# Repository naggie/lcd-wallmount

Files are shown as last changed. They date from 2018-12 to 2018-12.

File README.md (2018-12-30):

Unibezel is a tough, parametric bezel suitable for mounting a touchscreen on to
any wall. It has vents for passive cooling, holes for screws and cut-outs for
cabling. It is an evolution of my last [Amazon fire tablet mounting
system.][1]. It is built using [OpenSCAD][4].

The OpenSCAD file (bezel.scad) is set up to fit the [official Pi LCD
display][2] with a reversed [Raspberry Pi 3][2] behind, with space for a generic 5v
802.11af PoE adaptor. There are also configurations for the Amazon Fire 5
tablet -- though, beware -- do not leave the battery in the tablet when wall
mounted as it is a fire hazard. It is possible to power the tablet without the
battery providing the battery interface board is left connected.

The design has optional cut-outs for a 20mm conduit entry point, as well as
slopes on the top and bottom to increase toughness. Edges are mostly rounded
and chamfered to reduce stress concentration.

pi-display-bezel.stl is provided for your convenience. It is a pre-built stl of
the default configuration suitable for the official Pi display as above.

This design is the result of dozens of printed iterations. If you use this
design, please attribute the original repository at
https://github.com/naggie/unibezel

# Finishing process

I've printed this design with PLA on my 3d printer. It seems to work well -- no
supports are required when it is printed front-down.

Stop at step 5 if you're happy with a mediocre finish.

1. Coat generously with flexible car body filler (2 part, toxic!)
1. Sand flat with 80 or 120, round off sharp edges a small amount. Beware of dust.
1. Continue with P240, P400, P600 etc
1. Plastic Primer (2 or 3)
1. Gloss black (2 or 3)
1. Lacquer 3 or 4 coats
1. Sand P2000, P4000, P5000
1. Polish (car polish is good)
1. Wax
1. Detailer

# Images (Raspberry Pi display)

<p align="center">
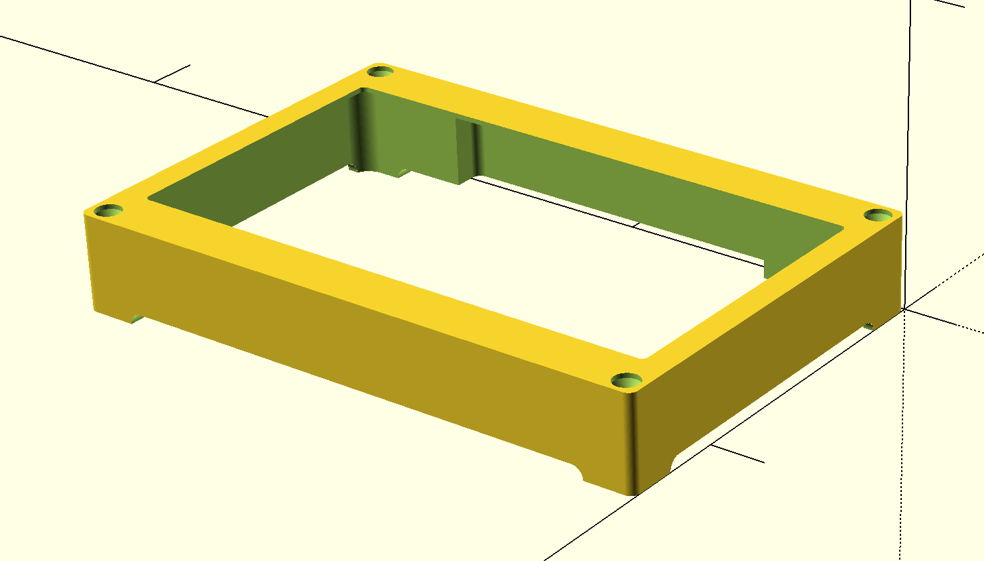
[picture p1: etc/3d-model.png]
  
</p>

<p align="center">
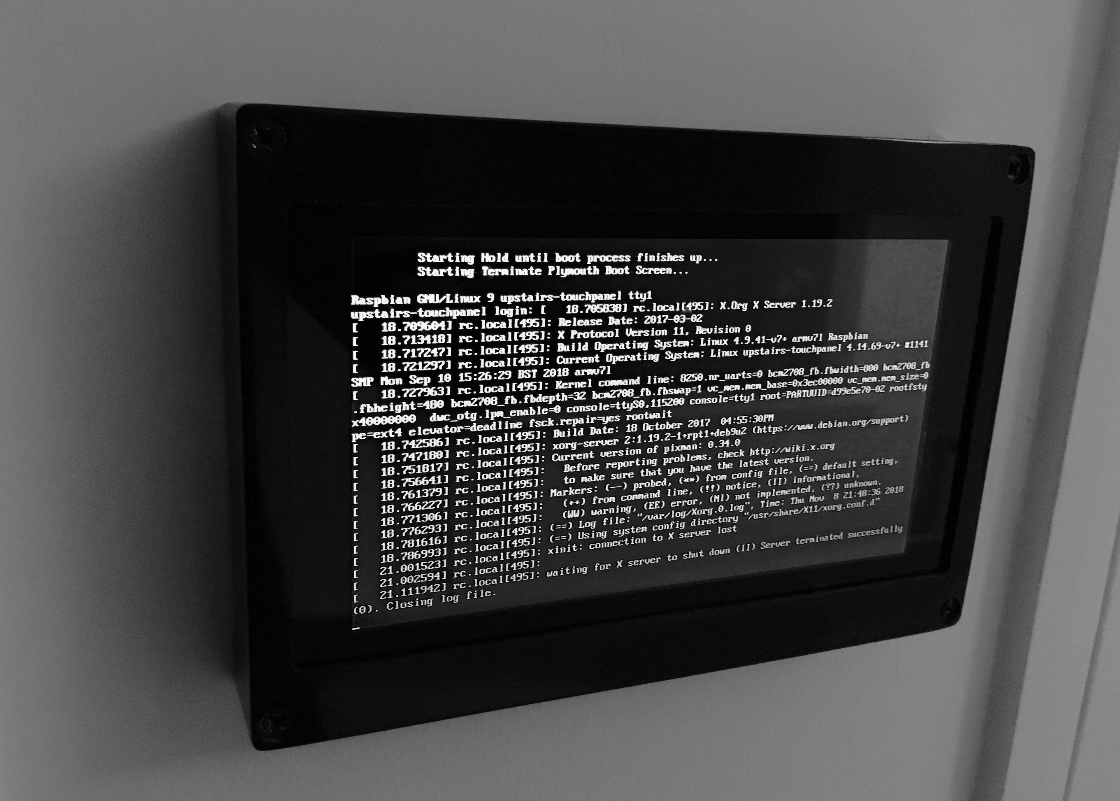
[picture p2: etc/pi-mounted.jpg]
  
</p>

<p align="center">
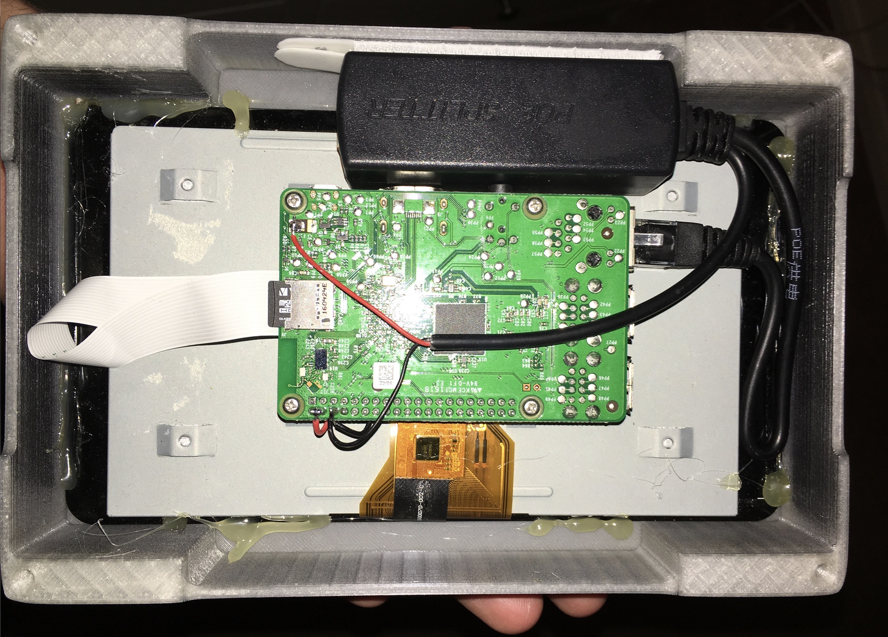
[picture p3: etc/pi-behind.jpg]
  
</p>

[1]: https://callanbryant.co.uk/post/dshome-2-control-panels/
[2]: https://www.raspberrypi.org/products/raspberry-pi-touch-display/
[3]: https://www.raspberrypi.org/products/raspberry-pi-3-model-b-plus/
[4]: https://www.openscad.org/

----

<br />This work is
licensed under a <a rel="license"
href="http://creativecommons.org/licenses/by/4.0/">Creative Commons Attribution
4.0 International License</a>.

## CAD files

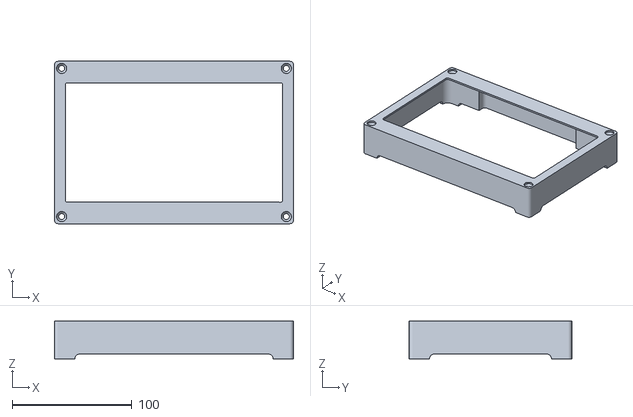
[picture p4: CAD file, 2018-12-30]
pi-display-bezel.stl
200.0 x 136.0 x 31.6

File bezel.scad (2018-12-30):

// https://github.com/OskarLinde/scad-utils/blob/master/morphology.scad
// empty in in /Users/<user>/Documents/OpenSCAD/libraries
// NOTE: Something I realised is symmetry is more important than spatial
// efficacy.
$fn = 200;

module rounded_cube(x,y,z,r) {
    linear_extrude(height=z) translate([r,r,0]) offset(r=r) square([x-2*r,y-2*r]);
}

// basic portrait bezel
// set tolerance to leave an appropriate gap for your manufacturing method
// https://www.3dprint-uk.co.uk/machine-accuracy/
// Tolerance is only given for the critical part, the tablet inlay
module bezel(
    // size of tablet/display (bounding box)
    x,y,z,
    // plastic covering screen: top, right, yframe, left (like CSS)
    // use to cover corner radius of tablet/display
    // use to cover non-display areas of tablet/display
    overhang=[3,3,3,3],
    // thickness of plastic covering screen
    rim_depth=2,
    // how far to move the rim down, use only to mount a flush screen from the front
    rim_inset=0,
    // frame intersecting y-axis
    yframe=10,
    // frame intersecting x-axis
    xframe=5,
    // move position of tablet/display along x-axis/y-axis to center a display with non-symmetric edges
    xshift=0,
    yshift=0,
    // internal cut out radius -- could match tablet/display corners. Important for flush displays
    internal_radius=2,
    // radius of rim, or support for flush screen
    rim_radius=2,
    slopes=false
) {


    difference() {
        hull() {
            if (slopes) {
                // experimental inefficient but cool looking slopes!
                translate([0, -z, 0]) rounded_cube(x+xframe*2, y+yframe*2 + 2*z, 6, 3);
            }

            // bounding box
            rounded_cube(x+xframe*2, y+yframe*2, z + rim_depth + rim_inset, 3);
        }

        // cut tablet, leaving a thin wall at front
        translate([xframe+xshift,yframe+yshift,-1]) rounded_cube(x,y,z+1.001,internal_radius);

        // cut front inset, eating into rim to make inset
        translate([xframe+xshift,yframe+yshift, z + rim_depth + 0.001]) rounded_cube(x, y, 500, internal_radius);

        // cut out window leaving a rim
        translate([xframe + overhang[3], yframe + overhang[2], -500])
            rounded_cube(x - overhang[1] - overhang[3], y-overhang[0] - overhang[2], 1000, rim_radius);
    }


}

// http://www.screwfix.com/p/fischer-plasterboard-plug-ldf-4-x-mm-pk100/81956
// http://www.screwfix.com/p/goldscrew-woodscrews-double-self-countersunk-4-x-25mm-pk200/17430
//
// Possibly use
// http://www.screwfix.com/p/dewalt-plasterboard-fixings-metal-25mm-pack-of-100/69132
// Which is not countersunk and therefore not self centering. Can tolerate alignment with bigger hole.
//
// It turns out the screws/plugs work great if you mount them right:
// 1. Attach bezel to wall with masking tape (level with spirit level)
// 2. Drill 4mm pilot holes
// 3. Remove bezel
// 4. Ream out holes with 6mm bit
// 5. Tap in plugs with hammer
// 6. Apply black nail polish to screw heads
//
// (6) was discovered to be better than using printed plastic screw head covers.
module countersunk_screwhole(head=8.5,diameter=4.5) {
    // head
    translate([0,0,-head*0.762/2]) cylinder(h=head*0.762,r1=0,r2=head/2,center=true);
    // shank
    // expand 10% for some play
    translate([0,0,-250/2]) cylinder(h=250,r1=diameter*0.55,r2=diameter*0.55,center=true);
    // plug hole
    translate([0,0,9.99]) cylinder(h=20,r=head/2,center=true);
}

module mountable_bezel(
    x,
    y,
    z,
    overhang=[3, 3, 3, 3],
    rim_depth=2,
    rim_inset=0,
    yframe=11,
    xframe=5,
    margin=1,
    xshift=0,
    yshift=0,
    internal_radius=2,
    rim_radius=2
) {
    x = x+margin;
    y = y+margin;
    z = z+margin;

    height = y + yframe*2;
    width = x+2*xframe;
    screw_z = z+rim_depth-1.5;

    difference() {
        bezel(
            x=x, y=y, z=z,
            overhang=overhang,
            rim_depth=rim_depth,
            rim_inset=rim_inset,
            yframe=yframe,
            xframe=xframe,
            xshift=xshift,
            yshift=yshift,
            internal_radius=internal_radius,
            rim_radius=rim_radius
        );
        translate([6,6,screw_z]) countersunk_screwhole(); // BL
        translate([width-6,6,screw_z]) countersunk_screwhole(); // BR
        translate([6,height-6,screw_z]) countersunk_screwhole(); // TL
        translate([width-6,height-6,screw_z]) countersunk_screwhole(); // TR


        // vents provide passive cooling (remove the back cover of tablet if
        // tablet is used) and also make the product look slimmer
        vent_margin = max(xframe + 5, yframe + 5);
        // x vents
        translate([-500,vent_margin,4]) rotate([0,90,0]) rounded_cube(12,y+yframe*2-2*vent_margin,1000,4);
        // y vents
        translate([vent_margin, 500, 4]) rotate([0,90,270]) rounded_cube(12,x+xframe*2-2*vent_margin,1000,4);

        // cable recesses, will only appear if frames are wide enough
        translate([3, yframe+y*0.2, z]) mirror([0,0,1]) rounded_cube(xframe*2 + x -6, y*0.6, 500, 3);
        translate([xframe+x*0.2, 3, z]) mirror([0, 0, 1]) rounded_cube(x*0.6, yframe*2 + y -6, 500, 3);

        // WIP -- conduit. TODO: thin wall to accept coupling, possibly also hex. Shorten vent conduit side.
        //translate([25, -1, 17]) rotate([270, 0, 0]) cylinder(yframe+2, d=20);
        //// spanner, recess
        //translate([14.5, 3, -0.001]) cube([21, yframe, 30]);
    }

}

module fire5_bezel() {
    difference() {
        mountable_bezel(115,191,10.6,rim_depth=1.5,yframe=12);

        // volume rocker (30-54)
        translate([30+5,10+192,0]) cube([24,1.8,10.8]);

        // microUSB solder connector + wire routing (25 45)
        translate([2*5+115-45,10+191,0]) cube([20,11,10.8]);

        // power button cutout
        translate([2*5+115-27,10+192,0]) cube([14,2,10.8]);

        // power button hole
        translate([2*5+115-20,10+191,10.6/2]) rotate([270,0,0]) cylinder(h=20,r=1.5);
    }
}

module nexus4_bezel() {
    difference() {
        mountable_bezel(68.7,133.9,9.1,[12,3,12,3],rim_depth=1.5,yframe=13);

        // volume rocker
        translate([5-1.8,12+79,0]) cube([1.8,23,0]);

        // microUSB solder connector + wire routing (25 45)
        translate([5+68.7/2-10,2,0]) cube([20,13,9]);

        // power button cutout
        translate([5+68.7,12+101,0]) cube([1.8,12,9]);

        // power button hole
        translate([5+68.7,12+101+6,9.1/2]) rotate([270,0,270]) cylinder(h=20,r=1.5);
    }
}

//fire5_bezel();
//nexus4_bezel();

// pi LCD
mountable_bezel(
    193,
    111,
    29,
    overhang=[6, 6, 6, 6],
    rim_depth=1.6,
    rim_inset=0,
    yframe=12,
    xframe=3,
    yshift=1,
    internal_radius=6.5
);

// pi LCD with inset bezel
//difference() {
//mountable_bezel(
//    193.5,
//    111.5,
//    26,
//    overhang=[7, 11, 3, 4],
//    rim_depth=2,
//    rim_inset=1.50,
//    yframe=12,
//    xframe=3,
//    yshift=1,
//    internal_radius=6.5,
//    rim_radius=1
//);
//
//translate([-1,-1,-1]) cube([300,300,25]);
//}

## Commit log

2016-07-14 reorg hierarchy
    [bezel.scad, bezel.stl]
2017-11-18 add gasket to add 2 hue switches over a blank plate
2017-11-19 widen holes for screws
2017-12-28 add prototype pi lcd bezel:wqa
    ked files:
    [bezel.scad, bezel.stl]
2017-12-28 resolve main z fighting
    [bezel.scad]
2017-12-28 add margin
    [bezel.scad]
2017-12-28 reimplement with offset instead of morphology
    [bezel.scad]
2017-12-28 add 10% to shank only
    [bezel.scad]
2017-12-28 reimplement countersunk screwhole
    [bezel.scad]
2017-12-28 solve for 82 degree countersink
    [bezel.scad]
2017-12-29 reduce margin
    [bezel.scad]
2017-12-29 reduce depth by 2mm
    [bezel.scad]
2017-12-29 save some of top/bottom/sides
    [bezel.scad]
2017-12-29 normalise to yframe and xframe
    [bezel.scad]
2017-12-29 fix vent calc, add xvent/yvent
    [bezel.scad]
2017-12-29 add x and y shift
    [bezel.scad]
2017-12-29 explain parameters
    [bezel.scad]
2017-12-29 add proto cable recesses
    [bezel.scad]
2017-12-30 fix cable recesses: stress risers
    [bezel.scad]
2017-12-30 tidy comments
    [bezel.scad]
2017-12-31 change margins
    [bezel.scad]
2017-12-31 tentative yshift
    [bezel.scad]
2018-01-01 larger screw head + more depth
    [bezel.scad]
2018-01-14 match inner display bezel
    [bezel.scad]
2018-01-14 always do xvents/yvents
    [bezel.scad]
2018-01-15 add support for inset
    [bezel.scad]
2018-01-17 add correct dimensions for display
    [bezel.scad]
2018-01-18 reduce depth due to flush LCD
    [bezel.scad]
2018-04-01 thicker vents
    [bezel.scad]
2018-04-01 add more material around corners
    [bezel.scad]
2018-04-01 correct vent radius+offset
    [bezel.scad]
2018-04-01 extend vents to similar edges
    [bezel.scad]
2018-04-02 start conduit hole
    [bezel.scad]
2018-04-02 consuit hole + recess/spanner
    [bezel.scad]
2018-04-18 add makefile for stl
    gcode in progress
2018-05-20 increase margin
    [bezel.scad]
2018-05-20 add optional cool looking slope
    [bezel.scad]
2018-07-02 move dsign into own subdir
    [bezel.scad]
2018-12-30 convert repository to exhibit bezel only
    [bezel.scad]
2018-12-30 add prebuilt pi display
    [pi-display-bezel.stl]

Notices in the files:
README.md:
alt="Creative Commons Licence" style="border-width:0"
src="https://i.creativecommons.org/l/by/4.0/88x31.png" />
